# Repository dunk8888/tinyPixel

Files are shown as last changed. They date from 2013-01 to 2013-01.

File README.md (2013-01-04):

# tinyPixel

tinyPixel is a compact, open-source, I2C-ready, BlinkM-compatible high-power RGB LED driver that can be individually pre-programmed or daisy-chainned and controlled by an Arduino or other microcontroller platform (like my Lumiboard!). tinyPixel uses the open-source cyz_rgb firmware to emulate the behavior of BlinkM modules, so it can be used with BlinkM software.

BlinkM modules are great, but quite expensive, especially if you want to use them in an installation (as they were intended). DIY alternatives, such as the Ghetto Pixel, are great but can be a burden to assemble at scale and are limited in the types of LEDs they use. I wanted something that was cheap, small and would be easy to assemble in a hurry.

## Board features
* Standard BlinkM-style interface (4-pin 0.1" male header for +, -, c and d lines).
* On-board 2W power resistors, so that 3W and 5W RGB LEDs can be driven.
* On-board ATTiny85 with cyz_rgb preloaded.
* On-board ULN2003 Darlington transistor array to sink large amounts of current for the RGB LED.
* 4-pin 0.1" male header to decouple RGB LED from main board (R,G, B and + lines).
* On-board 10uF capacitor to smooth the power out on each board.
* 4-pin Molex / ATX power connector to supply power.

## More information
Author's website: http://jason-webb.info
Project wiki: http://jason-webb.info/wiki/index.php?title=TinyPixel

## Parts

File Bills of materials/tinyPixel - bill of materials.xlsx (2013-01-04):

ID | Part name | Cost | Source URL
U1 | ATTINY85-20SU-ND | $1.18 | http://www.digikey.com/product-detail/en/ATTINY85-20SU/ATTINY85-20SU-ND/735470
IC1 | ULN2003ADR | $0.54 | http://www.digikey.com/product-detail/en/ULN2003ADR/296-1368-1-ND/404968
R1 | 6.8ohm, 2W resistor | $0.25 | http://www.digikey.com/product-detail/en/FMP200JR-52-6R8/6.8ZCT-ND/2059028
R2 | 3.9ohm, 2W resistor | $0.25 | http://www.digikey.com/product-detail/en/FMP200JR-52-3R9/3.9ZCT-ND/2059007
R3 | 3.9ohm, 2W resistor | $0.25 | http://www.digikey.com/product-detail/en/FMP200JR-52-3R9/3.9ZCT-ND/2059007
C1 | 10uF 0805 capacitor | $0.15 | http://www.digikey.com/product-detail/en/C2012Y5V1A106Z/445-1371-1-ND/567608
JP7 | 4-pin Molex socket | $0.83 | http://www.digikey.com/product-detail/en/0015244449/WM9132-ND/1190390
 | Total | $3.45

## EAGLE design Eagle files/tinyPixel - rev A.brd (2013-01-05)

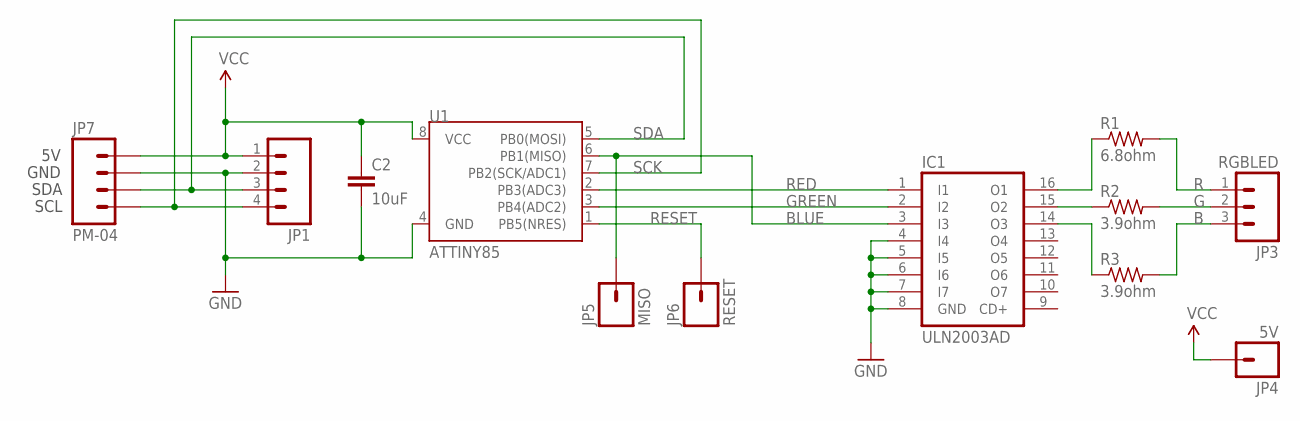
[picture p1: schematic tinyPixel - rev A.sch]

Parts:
C2: 10uF; 0805
IC1: ULN2003AD; SO16
JP1: M04PTH; 1X04
JP3: RGBLED; 1X03
JP4: 5V; 1X01
JP5: MISO; M01-SMD
JP6: RESET; M01-SMD
JP7: PM-04
R1: 6.8ohm; 0411/12
R2, R3: 3.9ohm; 0411/12
U1: ATTINY85; SO08-EIAJ

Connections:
B: JP3.3, R3.2
BLUE: IC1.3 (I3), JP5.P$2, U1.6 (PB1(MISO))
G: JP3.2, R2.2
GND: C2.2, IC1.4 (I4), IC1.5 (I5), IC1.6 (I6), IC1.7 (I7), IC1.8 (GND), JP1.2, JP7.P$3 (3), U1.4 (GND)
GREEN: IC1.2 (I2), U1.3 (PB4(ADC2))
unnamed: IC1.15 (O2), R2.1
unnamed: IC1.14 (O3), R3.1
unnamed: IC1.16 (O1), R1.1
R: JP3.1, R1.2
RED: IC1.1 (I1), U1.2 (PB3(ADC3))
RESET: JP6.P$2, U1.1 (PB5(NRES))
SCK: JP1.4, JP7.P$1 (1), U1.7 (PB2(SCK/ADC1))
SDA: JP1.3, JP7.P$2 (2), U1.5 (PB0(MOSI))
VCC: C2.1, JP1.1, JP4.1, JP7.P$4 (4), U1.8 (VCC)

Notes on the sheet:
GND
SDA
SCL

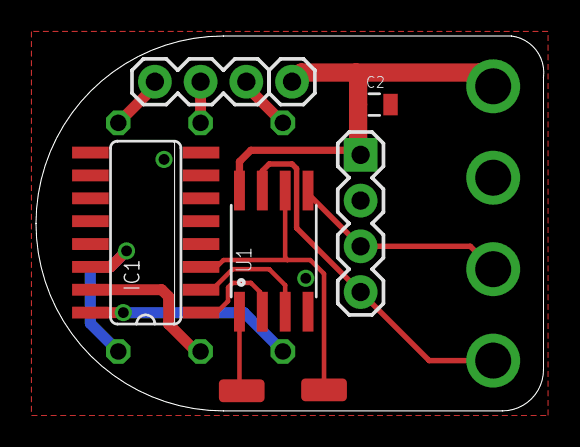
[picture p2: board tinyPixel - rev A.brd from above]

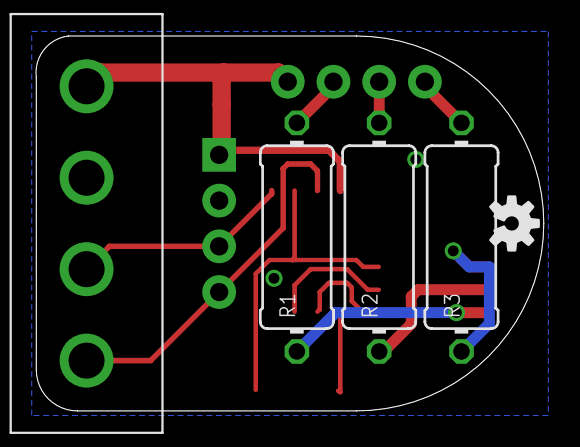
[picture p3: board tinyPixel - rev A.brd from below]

Board: 2 copper layers, 28.2 x 20.8 mm, 13 parts (5 on the bottom side), 14 nets.

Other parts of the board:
U$1: OSHW-LOGO-S

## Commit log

2013-01-04 Rev A board files, BOM, README updates
    [tinyPixel - bill of materials.xlsx, tinyPixel - rev A.brd, tinyPixel - rev A.sch]
2013-01-05 Updated Eagle files, BOM and Gerbers
    [tinyPixel - rev A.brd, tinyPixel - rev A.sch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]

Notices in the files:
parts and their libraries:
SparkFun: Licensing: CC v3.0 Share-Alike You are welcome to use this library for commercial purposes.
